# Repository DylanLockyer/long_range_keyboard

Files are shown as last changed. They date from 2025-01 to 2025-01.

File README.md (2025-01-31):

# long_range_keyboard
Creating a wireless keyboard with a range of 10km.

\*\*\* Not yet finished\*\*\*

The goal is to create a module which can be used for two purposes. One module can be connected over USB to a keyboard which will provide input to an STM32. The other circuit will be connected to a computer (in this case an Nvidia Jetson Nano) over usb. The STM32 on the second board will emulate an HID keyboard, and will relay the keystrokes from the keyboard which will be sent between the devices over LORA wireless communication. The board is in the PCB layout stage.

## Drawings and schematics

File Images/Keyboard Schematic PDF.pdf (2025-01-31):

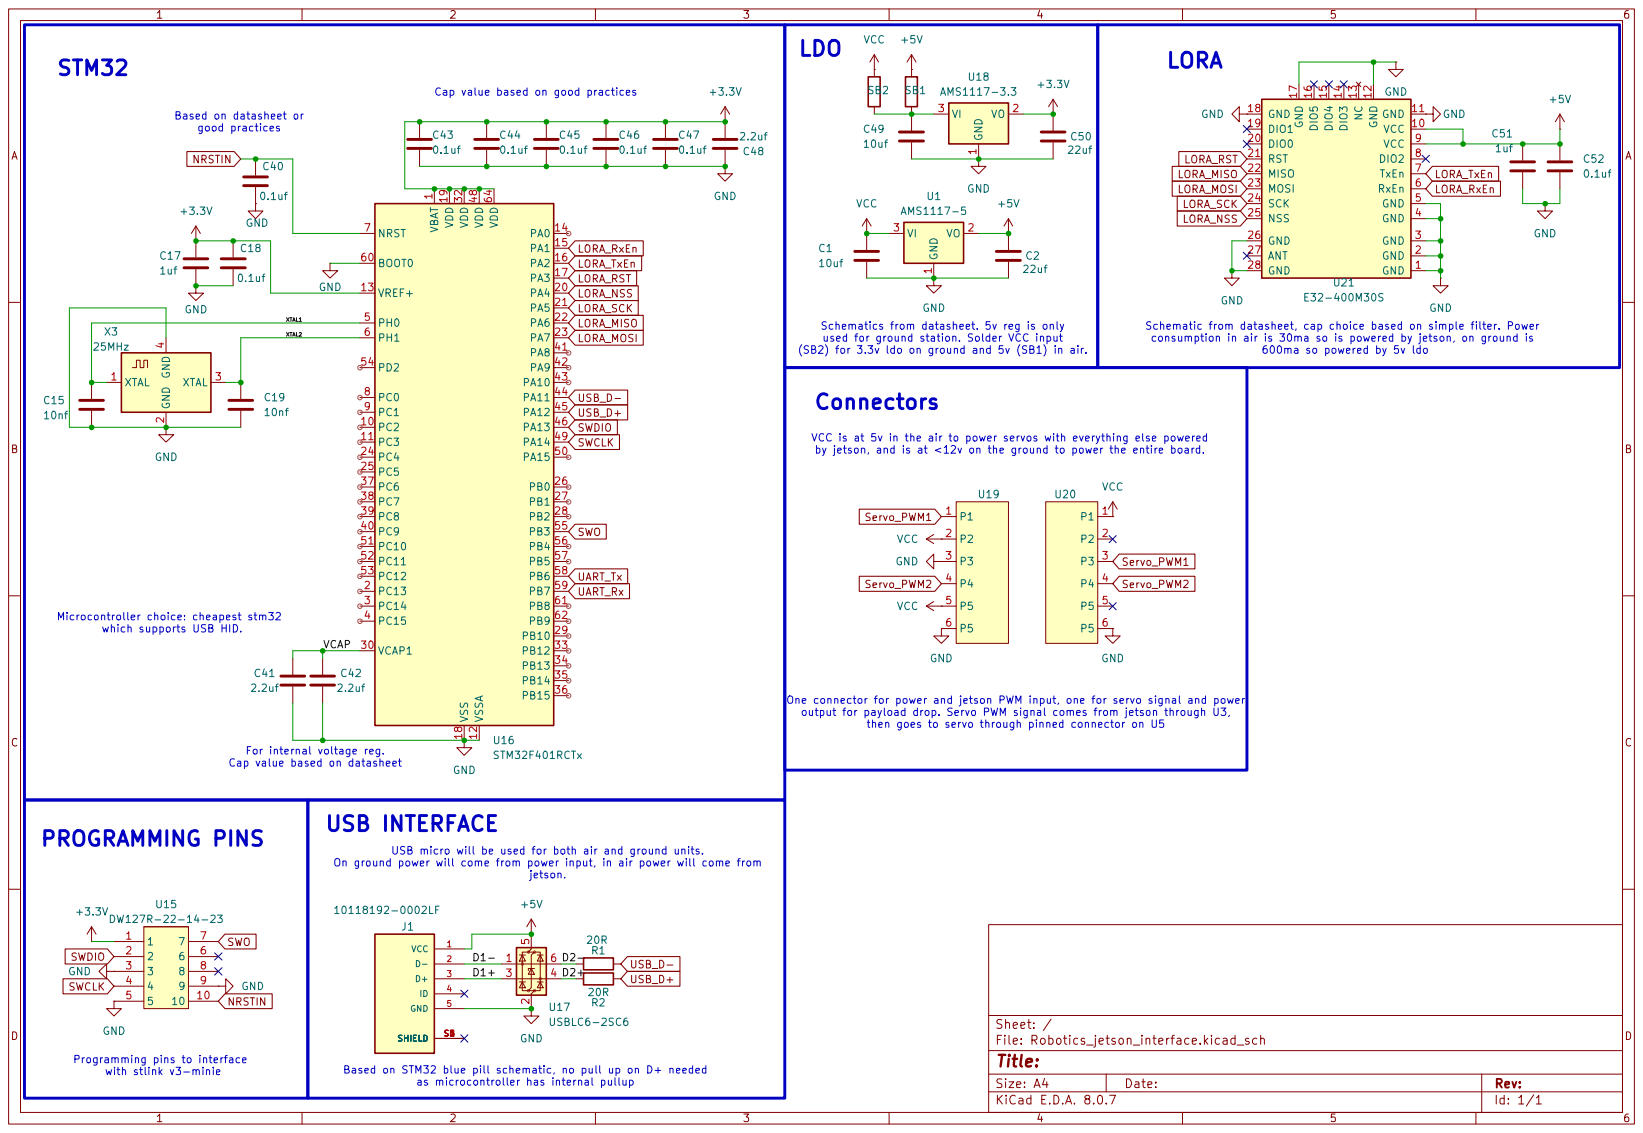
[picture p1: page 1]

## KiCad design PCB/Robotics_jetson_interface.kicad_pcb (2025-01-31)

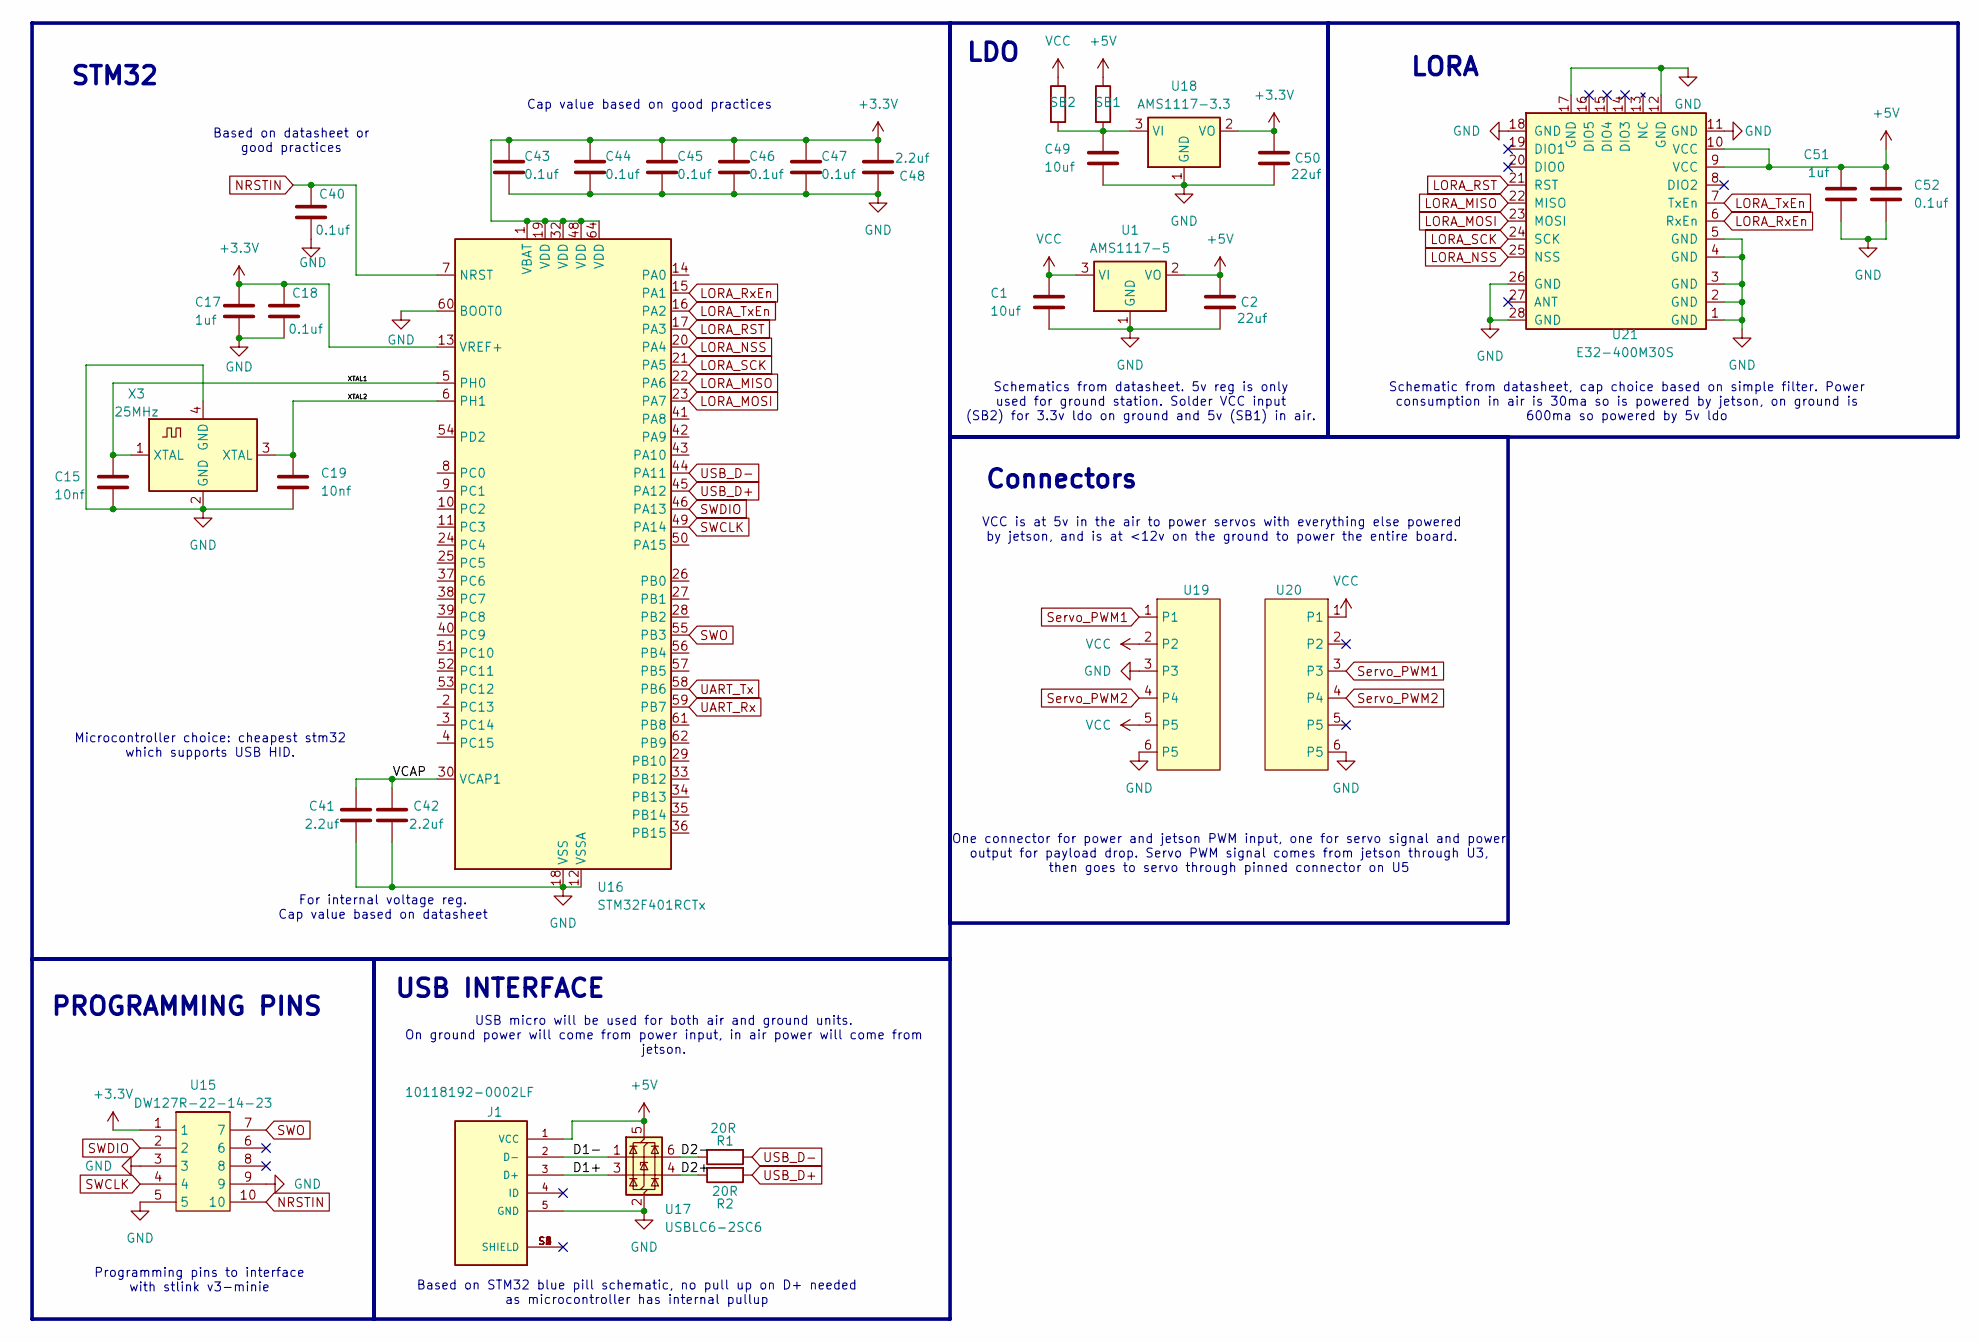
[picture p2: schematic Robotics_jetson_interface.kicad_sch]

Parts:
C1, C49: 10uf; C_0805_2012Metric
C2, C50: 22uf; C_0805_2012Metric_Pad1.18x1.45mm_HandSolder
C15, C19: 10nf; C_0805_2012Metric
C17, C51: 1uf; C_0603_1608Metric
C18, C40, C43, C44, C45, C46, C47, C52: 0.1uf; C_0402_1005Metric
C41, C42, C48: 2.2uf; C_0402_1005Metric
J1: 10118192-0002LF; AMPHENOL_10118192-0002LF; PARTREV B
R1, R2: 20R; R_0603_1608Metric
SB1, SB2: C_0603_1608Metric
U1: AMS1117-5; SOT-223-3_TabPin2
U15: DW127R-22-14-23
U16: STM32F401RCTx; LQFP-64_10x10mm_P0.5mm
U17: USBLC6-2SC6; SOT-23-6
U18: AMS1117-3.3; SOT-223-3_TabPin2
U19, U20: B06B-XASK-1-A
U21: E32-400M30S; E22-900M30S; PARTREV 1.4
X3: 25MHz; Crystal_SMD_3225-4Pin_3.2x2.5mm

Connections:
+3.3V: C17.1, C18.2, C43.1, C44.1, C45.1, C46.1, C47.1, C48.1, C50.1, U15.1, U16.1 (VBAT), U16.13 (VREF+), U16.19 (VDD), U16.32 (VDD), U16.48 (VDD), U16.64 (VDD), U18.2 (VO)
+5V: C2.1, C51.1, C52.1, J1.1 (VCC), SB1.1, U1.2 (VO), U17.5 (VBUS), U21.9 (VCC), U21.10 (VCC)
/D1+: J1.3 (D+), U17.3 (I/O2)
/D1-: J1.2 (D-), U17.1 (I/O1)
/D2+: R2.1, U17.4 (I/O2)
/D2-: R1.1, U17.6 (I/O1)
/VCAP: C41.2, C42.2, U16.30 (VCAP1)
/XTAL1: C15.1, U16.5 (PH0), X3.1 (XTAL)
/XTAL2: C19.1, U16.6 (PH1), X3.3 (XTAL)
GND: C1.2, C2.2, C15.2, C17.2, C18.1, C19.2, C40.1, C41.1, C42.1, C43.2, C44.2, C45.2, C46.2, C47.2, C48.2, C49.2, C50.2, C51.2, C52.2, J1.5 (GND), U1.1 (GND), U15.3, U15.5, U15.9, U16.12 (VSSA), U16.18 (VSS), U16.31 (VSS), U16.47 (VSS), U16.60 (BOOT0), U16.63 (VSS), U17.2 (GND), U18.1 (GND), U19.3, U19.6 (P5), U20.6 (P5), U21.1 (GND), U21.2 (GND), U21.3 (GND), U21.4 (GND), U21.5 (GND), U21.11 (GND), U21.12 (GND), U21.17 (GND), U21.18 (GND), U21.26 (GND), U21.28 (GND), X3.2 (GND), X3.4 (GND)
LORA_MISO: U16.22 (PA6), U21.22 (MISO)
LORA_MOSI: U16.23 (PA7), U21.23 (MOSI)
LORA_NSS: U16.20 (PA4), U21.25 (NSS)
LORA_RST: U16.17 (PA3), U21.21 (RST)
LORA_RxEn: U16.15 (PA1), U21.6 (RxEn)
LORA_SCK: U16.21 (PA5), U21.24 (SCK)
LORA_TxEn: U16.16 (PA2), U21.7 (TxEn)
NRSTIN: C40.2, U15.10, U16.7 (NRST)
unnamed: C49.1, SB1.2, SB2.2, U18.3 (VI)
SWCLK: U15.4, U16.49 (PA14)
SWDIO: U15.2, U16.46 (PA13)
SWO: U15.7, U16.55 (PB3)
Servo_PWM1: U19.1, U20.3
Servo_PWM2: U19.4, U20.4
UART_Rx: U16.59 (PB7)
UART_Tx: U16.58 (PB6)
USB_D+: R2.2, U16.45 (PA12)
USB_D-: R1.2, U16.44 (PA11)
VCC: C1.1, SB2.1, U1.3 (VI), U19.2, U19.5, U20.1

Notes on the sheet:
USB INTERFACE
Schematic from datasheet, cap choice based on simple filter. Power consumption in air is 30ma so is powered by jetson, on ground is 600ma so powered by 5v ldo
PROGRAMMING PINS
LORA
Schematics from datasheet. 5v reg is only used for ground station. Solder VCC input (SB2) for 3.3v ldo on ground and 5v (SB1) in air.
Based on datasheet or good practices
Based on STM32 blue pill schematic, no pull up on D+ needed as microcontroller has internal pullup
VCC is at 5v in the air to power servos with everything else powered by jetson, and is at <12v on the ground to power the entire board.
STM32
Microcontroller choice: cheapest stm32 which supports USB HID.
Connectors
For internal voltage reg. Cap value based on datasheet
One connector for power and jetson PWM input, one for servo signal and power output for payload drop. Servo PWM signal comes from jetson through U3, then goes to servo through pinned connector on U5
Cap value based on good practices
LDO
USB micro will be used for both air and ground units. On ground power will come from power input, in air power will come from jetson.
Programming pins to interface with stlink v3-minie

Board: 2 copper layers, 33 parts (22 on the bottom side), 27 nets, no tracks yet.

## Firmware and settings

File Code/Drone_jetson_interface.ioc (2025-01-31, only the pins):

Mcu.UserName=STM32F401RCTx
PA1.GPIO_Label=LORA_RxEn
PA1.Signal=GPIO_Output
PA10.Signal=USB_OTG_FS_ID
PA11.Signal=USB_OTG_FS_DM
PA12.Signal=USB_OTG_FS_DP
PA13.Signal=SYS_JTMS-SWDIO
PA14.Signal=SYS_JTCK-SWCLK
PA2.GPIO_Label=LORA_TxEn
PA2.Signal=GPIO_Output
PA3.GPIO_Label=LORA_RST
PA3.Signal=GPIO_Output
PA4.Signal=SPI1_NSS
PA5.Signal=SPI1_SCK
PA6.Signal=SPI1_MISO
PA7.Signal=SPI1_MOSI
PA9.Signal=USB_OTG_FS_VBUS
PB3.Signal=SYS_JTDO-SWO
PC6.Signal=S_TIM3_CH1
PC7.Signal=S_TIM3_CH2
PC8.GPIO_Label=MOTOR_ERROR
PC8.Signal=GPIO_Input
PC9.GPIO_Label=MOTOR_SLEEP
PC9.Signal=GPIO_Output
